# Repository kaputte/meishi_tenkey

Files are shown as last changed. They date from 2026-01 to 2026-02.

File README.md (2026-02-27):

# meishi_tenkey

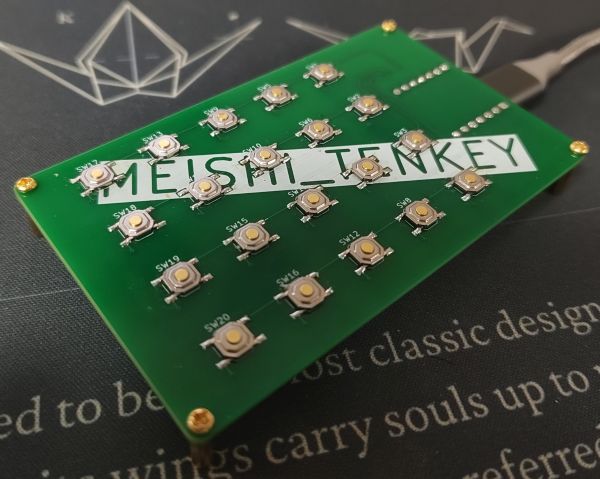
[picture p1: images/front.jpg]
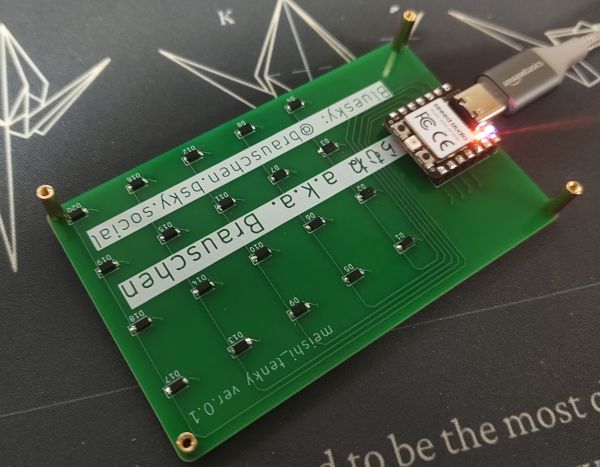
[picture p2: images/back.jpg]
 

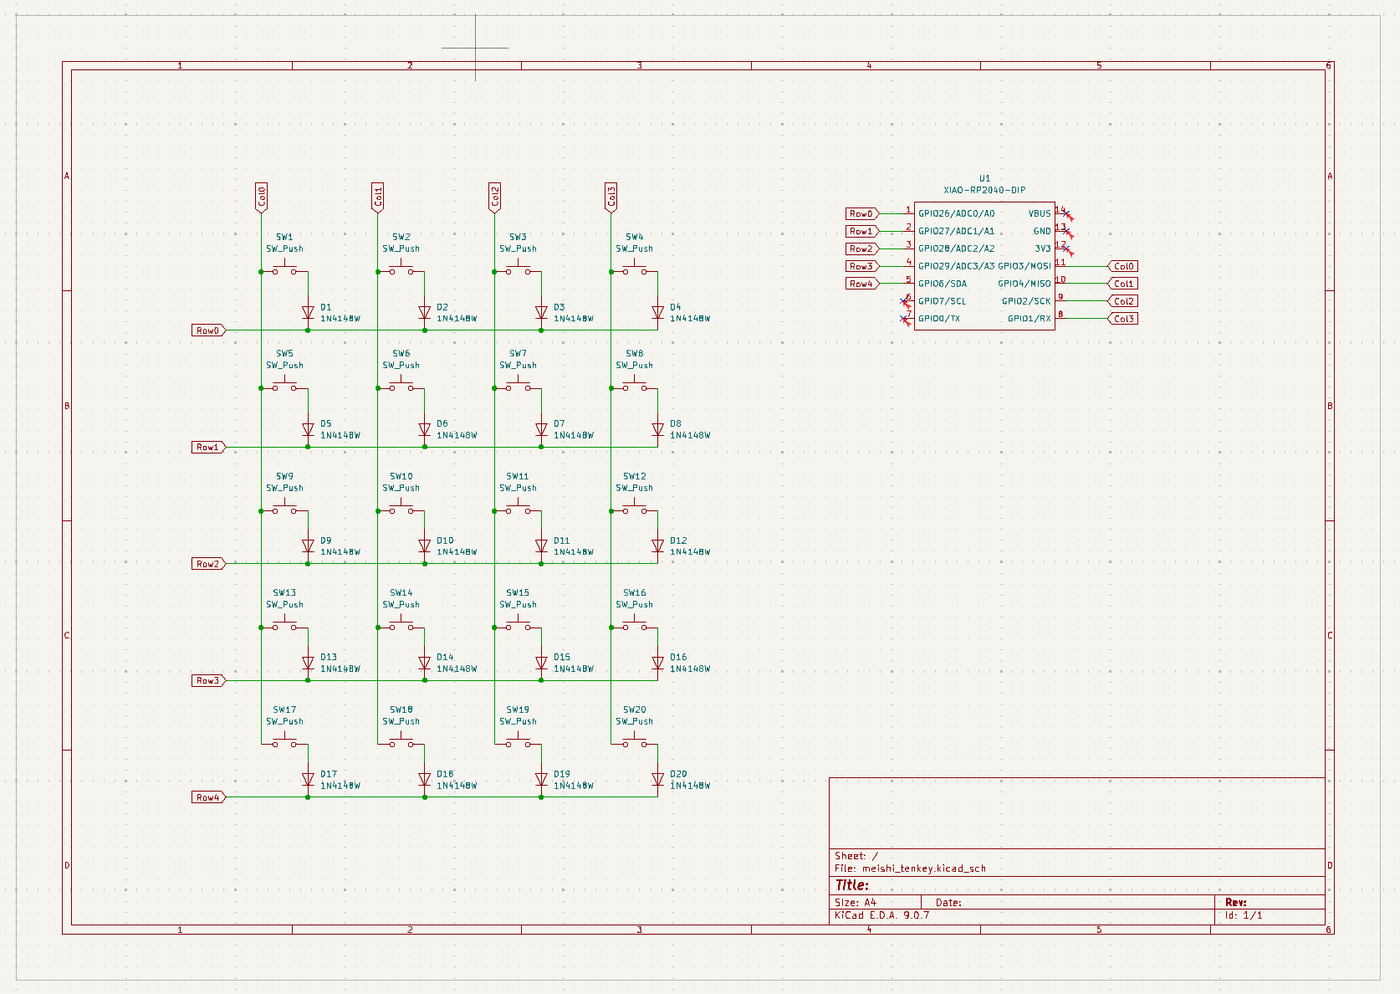
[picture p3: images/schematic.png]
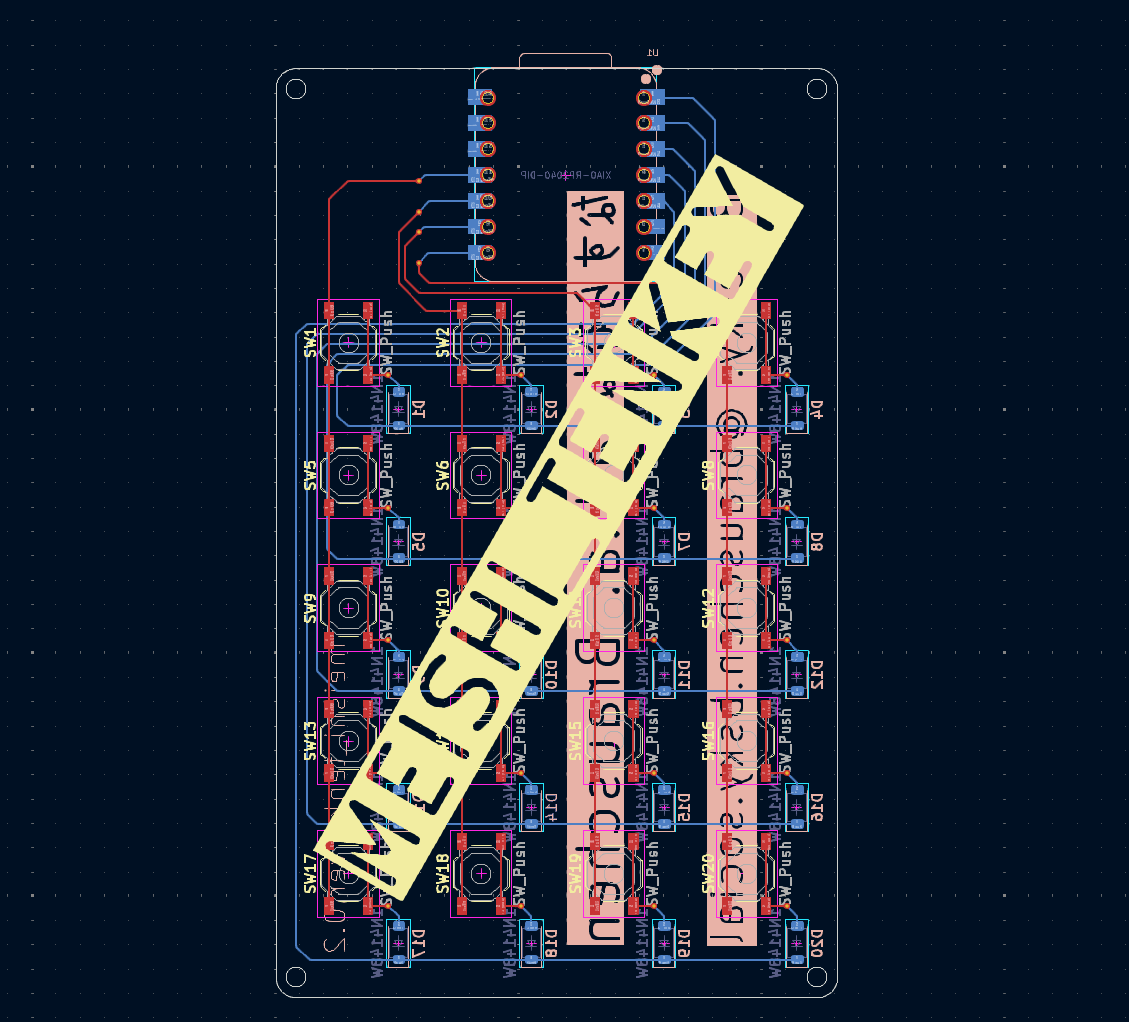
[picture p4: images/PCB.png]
 

XIAO RP2040 を使用した 5x4 テンキーキーボード

- QMKファームウェア対応
- 2レイヤー（テンキー / ナビゲーション）

## 注意事項

v0.1のPCBではマイコンのスルーホールの間隔を間違えており、Xiaoのピンヘッダより僅かに広いです。先にピンヘッダとマイコンを挿してからハンダ付けしてください。Xiaoのピンヘッダを先に実装するとPCBに挿さらなくなります。

> **v0.2で修正済み。** v0.2以降のPCBではこの問題は解消されています。

## レイアウト

```
┌───┬───┬───┬───┐
│NLk│ / │ * │ - │
├───┼───┼───┼───┤
│ 7 │ 8 │ 9 │ + │
├───┼───┼───┼───┤
│ 4 │ 5 │ 6 │ + │
├───┼───┼───┼───┤
│ 1 │ 2 │ 3 │Ent│
├───┼───┼───┼───┤
│ 0 │Fn │ . │Ent│
└───┴───┴───┴───┘
```

## 部品表

| 部品 | 数量 | 備考 |
|---|---|---|
| XIAO RP2040 | 1 | ピンヘッダで取り付け |
| タクトスイッチ | 20 | 薄型（厚さ約1.5mm） |
| ダイオード（1N4148W） | 20 | |

## ファームウェア

### 書き込み方法

1. XIAO RP2040 の B ボタンを押しながら R ボタンを押す
2. PC にリムーバブルドライブとしてマウントされる
3. `qmk_firmware/meishi_tenkey_default.uf2` をドライブにコピー

### キーマップのカスタマイズ

レイアウトを変更したい場合は、Linux または WSL 上に QMK 環境を構築し、以下の手順で行ってください。

1. `./qmk_firmware/keyboards/meishi_tenkey` を QMK 本体の `keyboards/` 以下にコピー
2. `keymaps/default/keymap.c` を編集
3. `qmk compile -kb meishi_tenkey -km default` でビルド
4. 出力された `.uf2` ファイルを XIAO RP2040 に書き込み

## PCB設計環境

KiCad 9.0.7 で編集しています。

- [Xiao_Kicad_Library](https://github.com/Seeed-Studio/Xiao_Kicad_Library) - XIAO RP2040 のシンボル / フットプリント

## ライセンス

GPL-2.0

ハードウェア部分（KiCad）については、将来的に CERN-OHL-S へ変更する可能性があります。

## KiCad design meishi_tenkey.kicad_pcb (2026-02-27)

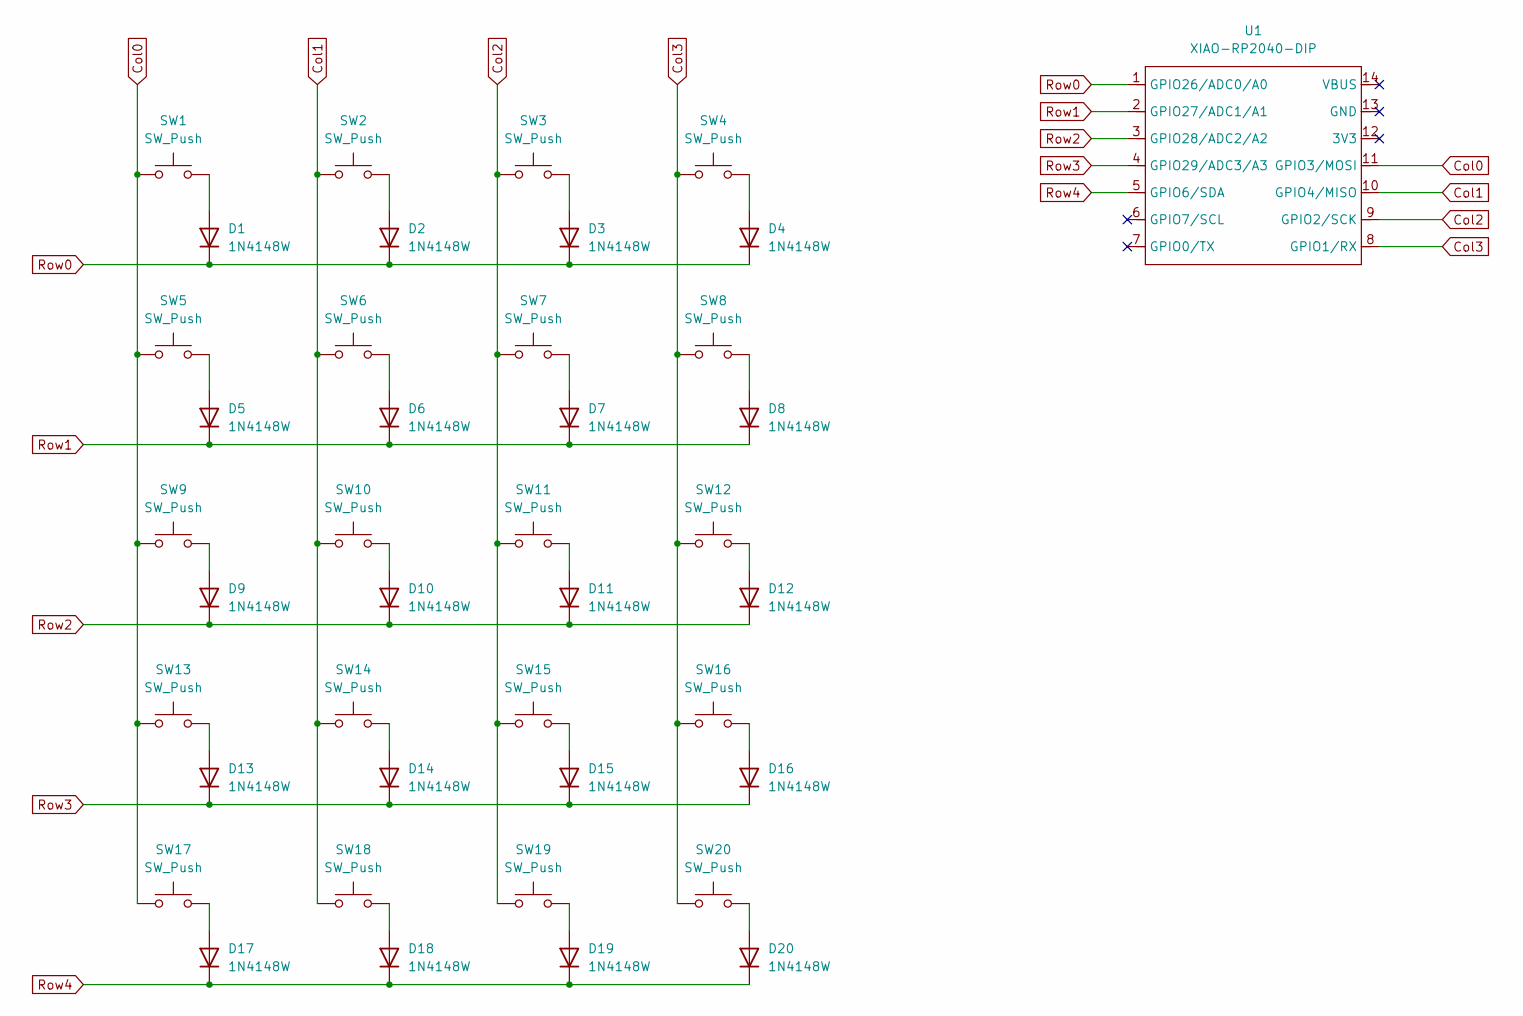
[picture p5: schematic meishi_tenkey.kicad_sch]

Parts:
D1, D2, D3, D4, D5, D6, D7, D8, D9, D10, D11, D12, D13, D14, D15, D16, D17, D18, D19, D20: 1N4148W; D_SOD-123
SW1, SW2, SW3, SW4, SW5, SW6, SW7, SW8, SW9, SW10, SW11, SW12, SW13, SW14, SW15, SW16, SW17, SW18, SW19, SW20: SW_Push; SW_SPST_TL3342
U1: XIAO-RP2040-DIP

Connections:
Col0: SW1.1, SW5.1, SW9.1, SW13.1, SW17.1, U1.11 (GPIO3/MOSI)
Col1: SW2.1, SW6.1, SW10.1, SW14.1, SW18.1, U1.10 (GPIO4/MISO)
Col2: SW3.1, SW7.1, SW11.1, SW15.1, SW19.1, U1.9 (GPIO2/SCK)
Col3: SW4.1, SW8.1, SW12.1, SW16.1, SW20.1, U1.8 (GPIO1/RX)
unnamed: D1.2 (A), SW1.2
unnamed: D2.2 (A), SW2.2
unnamed: D3.2 (A), SW3.2
unnamed: D4.2 (A), SW4.2
unnamed: D5.2 (A), SW5.2
unnamed: D6.2 (A), SW6.2
unnamed: D7.2 (A), SW7.2
unnamed: D8.2 (A), SW8.2
unnamed: D9.2 (A), SW9.2
unnamed: D10.2 (A), SW10.2
unnamed: D11.2 (A), SW11.2
unnamed: D12.2 (A), SW12.2
unnamed: D13.2 (A), SW13.2
unnamed: D14.2 (A), SW14.2
unnamed: D15.2 (A), SW15.2
unnamed: D16.2 (A), SW16.2
unnamed: D17.2 (A), SW17.2
unnamed: D18.2 (A), SW18.2
unnamed: D19.2 (A), SW19.2
unnamed: D20.2 (A), SW20.2
Row0: D1.1 (K), D2.1 (K), D3.1 (K), D4.1 (K), U1.1 (GPIO26/ADC0/A0)
Row1: D5.1 (K), D6.1 (K), D7.1 (K), D8.1 (K), U1.2 (GPIO27/ADC1/A1)
Row2: D9.1 (K), D10.1 (K), D11.1 (K), D12.1 (K), U1.3 (GPIO28/ADC2/A2)
Row3: D13.1 (K), D14.1 (K), D15.1 (K), D16.1 (K), U1.4 (GPIO29/ADC3/A3)
Row4: D17.1 (K), D18.1 (K), D19.1 (K), D20.1 (K), U1.5 (GPIO6/SDA)

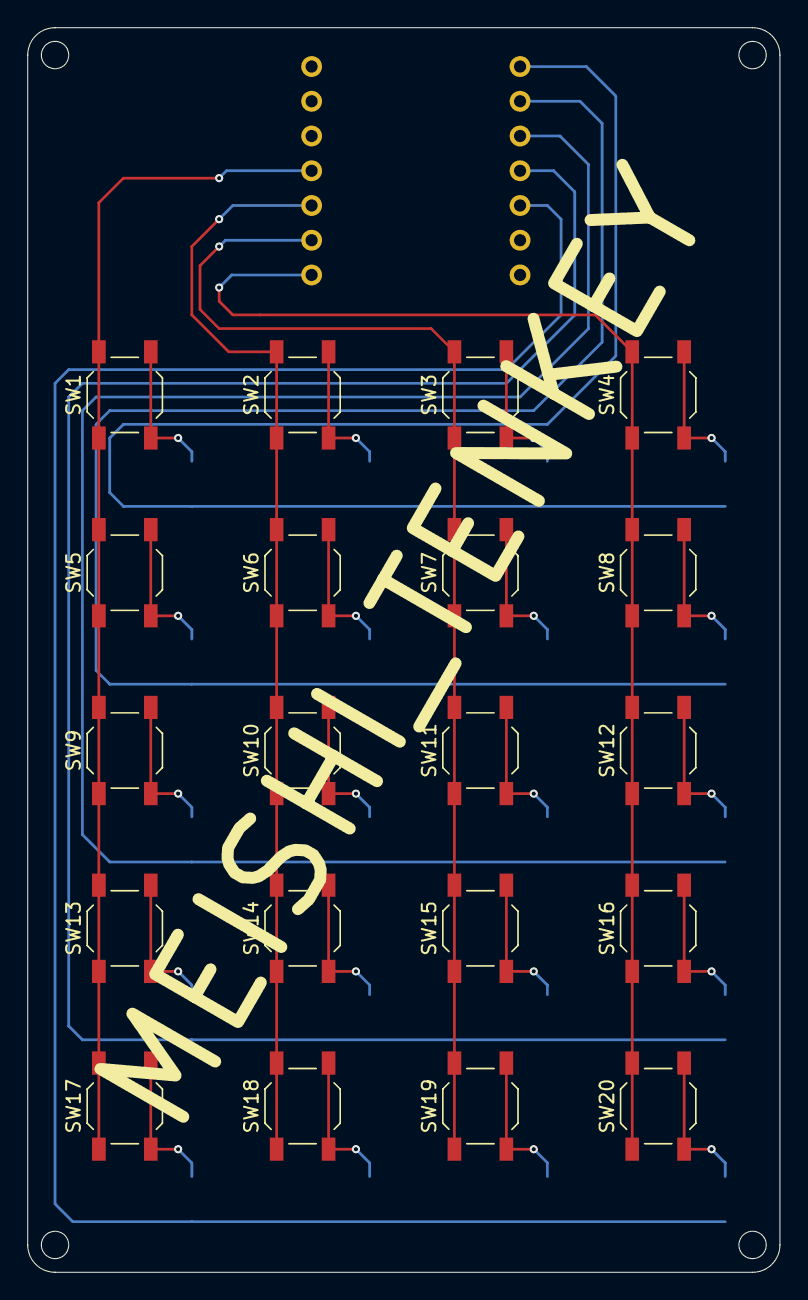
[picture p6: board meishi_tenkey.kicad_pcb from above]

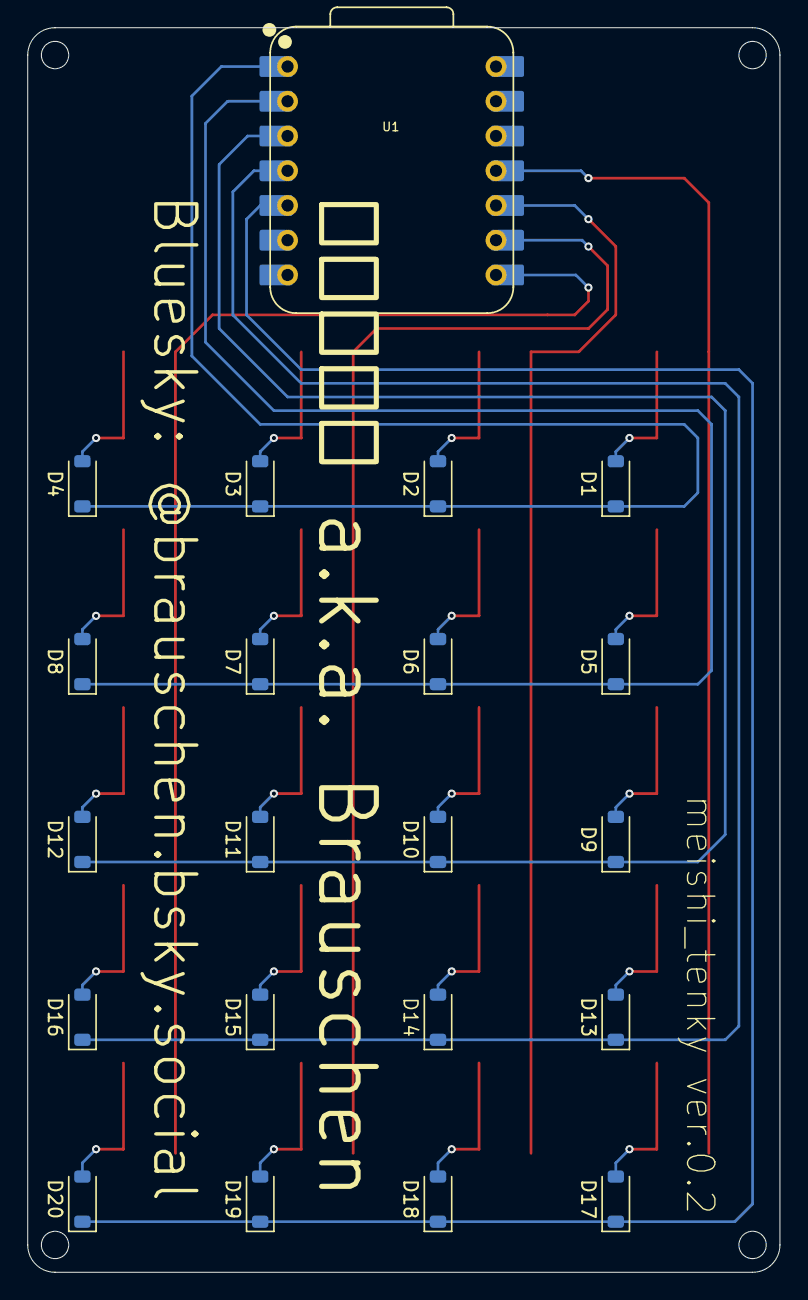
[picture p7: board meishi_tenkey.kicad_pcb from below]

Board: 2 copper layers, 55.0 x 91.0 mm, 41 parts (21 on the bottom side), 29 nets.

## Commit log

2026-01-28 Initial commit: meishi_tenkey 5x4 numpad keyboard
    - KiCad PCB design files and gerber outputs
    - QMK firmware with RP2040 support
    - Default keymap with numpad and navigation layers
    [meishi_tenkey-B_Cu.gbr, meishi_tenkey-B_Mask.gbr, meishi_tenkey-B_Silkscreen.gbr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]
2026-01-29 docs: add schematic and PCB images
2026-01-29 docs: remove PCB editor grid setting
2026-01-29 docs: simplify PCB design section to only required library
2026-01-29 docs: add KiCad version info
2026-01-29 chore: add KiCad lock files to gitignore
2026-02-08 README.md の更新
2026-02-27 fix: correct MCU through-hole pitch in footprint (v0.2)
    Fix incorrect through-hole spacing for the microcontroller footprint.
    Regenerate all gerber files with the corrected PCB design.
    Update README to note the fix for v0.1 users.
    [meishi_tenkey-B_Cu.gbr, meishi_tenkey-B_Mask.gbr, meishi_tenkey-B_Silkscreen.gbr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]
2026-02-27 chore: minor adjustments to PCB design and update images
    [meishi_tenkey-B_Cu.gbr, meishi_tenkey-B_Mask.gbr, meishi_tenkey-B_Silkscreen.gbr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]
2026-02-27 chore: add KiCad autosave files to gitignore
